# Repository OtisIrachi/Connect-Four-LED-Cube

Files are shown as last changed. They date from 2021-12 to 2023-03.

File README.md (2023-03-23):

# Connect four led cube
Connect Four Game using Wemos D1 Mini
4x4x4 LED Cube with encoder/PB to select game players and set moves.

Source Code, Schematic, Project Box STL Files, and BOM provided by RCI

Requires the following arduino library files:

Adafruit_NeoPixel.h

Adafruit_GFX.h

Adafruit_NeoMatrix.h

ESPRotarySet.h

connect4x4x4cubeschematic

connect4x4x4ledwiring

A few notes.....
1.  The WS2811 series LED's do not work well with WEMOS D1 GPIO outputs.  The digital output to the WS2811 is too low
    to reliably set the ws2811 shift register.  Remove the surface mount on-board rectifier diode (black diode near USB connector).
    Solder a jumper wire in its place.  The WEMOS D1 will now have enough voltage to drive the D-IN for the WS2811 LED's.
2.  Battery used in the project is a 3.7V 1000 mA lithium polymer, but any 3.7V 1000 mA battery will work. https://www.amazon.com/YTKavq-1000mAh-Battery-Rechargeable-Connector/dp/B08TTTL5BV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 
3.  Charger is a 1A USB Lithium Polymer Charger module, but any USB 1000ma charger will work.  https://www.amazon.com/CHENBO-Lithium-Battery-Charging-Protection/dp/B06XCXPY86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
4.  Proto board that fits in STL Case was found at Amazon, https://www.amazon.com/ElectroCookie-Prototype-Snappable-Electronics-Gold-Plated/dp/B081QYPHHP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

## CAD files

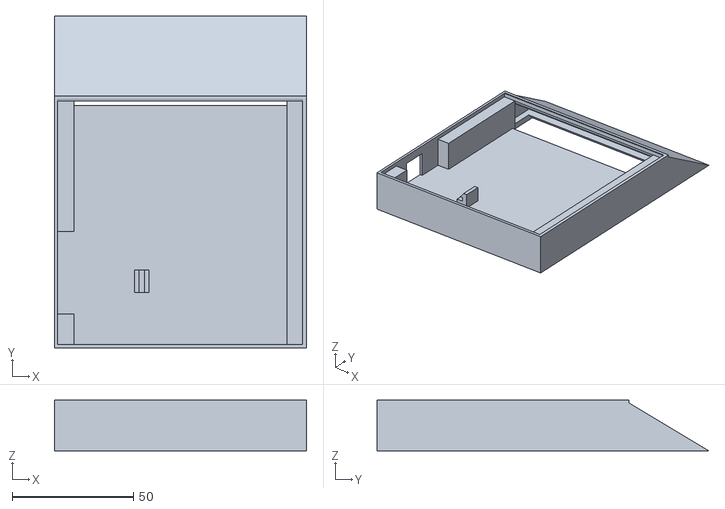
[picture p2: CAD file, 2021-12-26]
NeoCube Base.stl
104.0 x 137.0 x 21.0

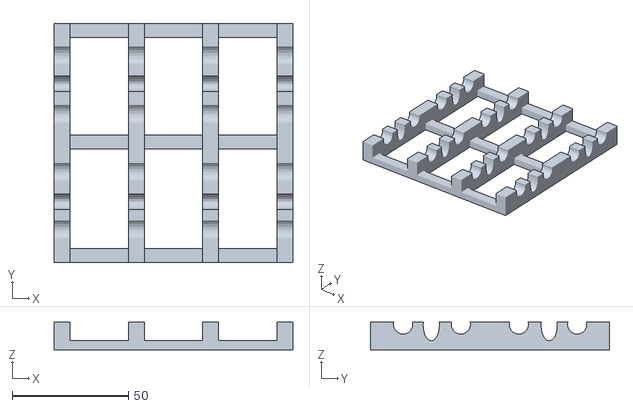
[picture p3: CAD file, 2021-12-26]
LED Jig Side.stl
103.0 x 103.0 x 12.0

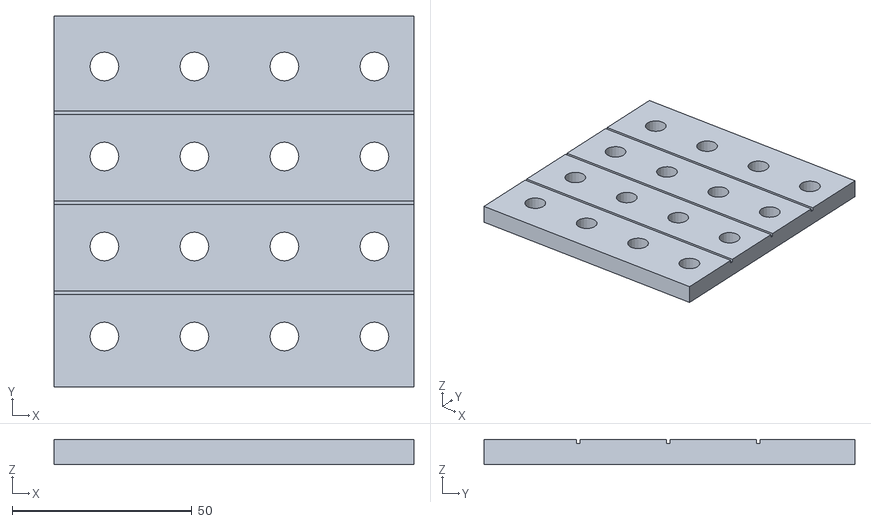
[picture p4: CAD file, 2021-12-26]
LED Jig 8mm.stl
100.0 x 103.0 x 7.00

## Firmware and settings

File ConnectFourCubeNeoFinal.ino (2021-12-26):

//*******************************************************************************
// ConnectFourCubeNeoFinal.ino
// Progressive Version of the Cube
// Connect Four RGB Cube Game
// If encoder has threads on shaft, use ESPRotarySet.h
// by RCI
//
// Edits:
//      10-11-2016
//         Added Player color choice check and flash yellow when same color selected.
//      3-18-2017
//         Cleaned up variable types,  reversed encoder direction - RCI.
//      12-24-2019
//         Fixed counter loop issue while displaying random rain - RCI.
//      11-10-2020
//         Added RefreshCube() call to FlashRow Routine.  Not sure why flash stopped
//         working - RCI.
//      12-24-2020 Changed EncoderHalfStep.h to ErriezRotaryHalfStep.h
//      1-16-2021 Redesigned cube for WS2812 Neopixels  
//      8-9-2021 Changed Encoder Driver to ESPRotarySet.h for threaded shaft type
//                ESPRotarySet added setPosition(int pos)
//*******************************************************************************
#include <Adafruit_NeoPixel.h>
#include <Adafruit_GFX.h>
#include <Adafruit_NeoMatrix.h>
//#include <ErriezRotaryHalfStep.h> 
#include <ESPRotarySet.h>
//***** Variables **************************
unsigned char flag;
unsigned char pos, next_slot, current_pos, last_pos;
unsigned char result;
signed int EncVal;
signed int countLast = 0;
unsigned char ColorChoice;
unsigned char next_player;
unsigned int counter;
unsigned int buttoncount;
unsigned char player;
unsigned char win[5];
unsigned char PlayerColor[3][3];
unsigned char MemoryColors[66][4]; 

#define PIN 4            // D2
#define BUTTON 14        // D5
#define ROTARY_PIN1  12  // D7
#define ROTARY_PIN2  13  // D6
#define CLICKS_PER_STEP   4   // this number depends on your rotary encoder 

#define MATRIX_WIDTH 4
#define MATRIX_HEIGHT 4
#define STARTING_PIXEL 1
#define MIN_ENC_VAL 1
#define MAX_ENC_VAL 64

#define LED_COUNT 64
#define num_of_pixels 64  //(sacrificial LED)

#define red       255, 0, 0
#define green     0, 255, 0
#define blue      0, 0, 255
#define black     0 ,0, 0
#define grey      1, 1, 1
#define dimwhite  1, 1, 1
#define midwhite  127, 127, 127
#define white     255, 255, 255
#define coolwhite 255, 255, 255
#define yellow    255, 138, 0
#define cyan      0, 255, 255
#define magenta   255, 0, 255
#define gold      255, 90, 0
#define orange    220, 40, 0
#define olive     100, 220, 47
#define turq      35, 255, 30
#define lime      15, 70, 10
#define skyblue   65, 176, 255
#define purple    70, 0, 120

//Matrix to Cube mapping 
unsigned char ZX[5][4]= 
{ 
 {0,0,0,0},
 {4,4,4,4},
 {8,8,8,8},
 {12,12,12,12}
};

//****************************************************                           
const unsigned char TempPos[65][4] = {
                            {0, 0, 0, 0},  // dummy
                            {0, 0, 0, 0},  // 1
                            {0, 1, 0, 0},  // 2
                            {0, 2, 0, 0},  // 3
                            {0, 3, 0, 0},  // 4
                            {0, 0, 1, 0},  // 5
                            {0, 1, 1, 0},  // 6
                            {0, 2, 1, 0},  // 7
                            {0, 3, 1, 0},  // 8
                            {0, 0, 2, 0},  // 9
                            {0, 1, 2, 0},  // 10
                            {0, 2, 2, 0},  // 11
                            {0, 3, 2, 0},  // 12
                            {0, 0, 3, 0},  // 13
                            {0, 1, 3, 0},  // 14
                            {0, 2, 3, 0},  // 15
                            {0, 3, 3, 0},  // 16 
                            {1, 0, 0, 0},  // 1
                            {1, 1, 0, 0},  // 2
                            {1, 2, 0, 0},  // 3
                            {1, 3, 0, 0},  // 4
                            {1, 0, 1, 0},  // 5
                            {1, 1, 1, 0},  // 6
                            {1, 2, 1, 0},  // 7
                            {1, 3, 1, 0},  // 8
                            {1, 0, 2, 0},  // 9
                            {1, 1, 2, 0},  // 10
                            {1, 2, 2, 0},  // 11
                            {1, 3, 2, 0},  // 12
                            {1, 0, 3, 0},  // 13
                            {1, 1, 3, 0},  // 14
                            {1, 2, 3, 0},  // 15
                            {1, 3, 3, 0},  // 16 
                            {2, 0, 0, 0},  // 1
                            {2, 1, 0, 0},  // 2
                            {2, 2, 0, 0},  // 3
                            {2, 3, 0, 0},  // 4
                            {2, 0, 1, 0},  // 5
                            {2, 1, 1, 0},  // 6
                            {2, 2, 1, 0},  // 7
                            {2, 3, 1, 0},  // 8
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
                            }; 

//****************************************************  
unsigned char LEDPos[65][4] = {
                            {0, 0, 0, 0},  // dummy
                            {0, 0, 0, 0},  // 1
                            {0, 1, 0, 0},  // 2
                            {0, 2, 0, 0},  // 3
                            {0, 3, 0, 0},  // 4
                            {0, 0, 1, 0},  // 5
                            {0, 1, 1, 0},  // 6
                            {0, 2, 1, 0},  // 7
                            {0, 3, 1, 0},  // 8
                            {0, 0, 2, 0},  // 9
                            {0, 1, 2, 0},  // 10
                            {0, 2, 2, 0},  // 11
                            {0, 3, 2, 0},  // 12
                            {0, 0, 3, 0},  // 13
                            {0, 1, 3, 0},  // 14
                            {0, 2, 3, 0},  // 15
                            {0, 3, 3, 0},  // 16 
                            {1, 0, 0, 0},  // 1
                            {1, 1, 0, 0},  // 2
                            {1, 2, 0, 0},  // 3
                            {1, 3, 0, 0},  // 4
                            {1, 0, 1, 0},  // 5
                            {1, 1, 1, 0},  // 6
                            {1, 2, 1, 0},  // 7
                            {1, 3, 1, 0},  // 8
                            {1, 0, 2, 0},  // 9
                            {1, 1, 2, 0},  // 10
                            {1, 2, 2, 0},  // 11
                            {1, 3, 2, 0},  // 12
                            {1, 0, 3, 0},  // 13
                            {1, 1, 3, 0},  // 14
                            {1, 2, 3, 0},  // 15
                            {1, 3, 3, 0},  // 16 
                            {2, 0, 0, 0},  // 1
                            {2, 1, 0, 0},  // 2
                            {2, 2, 0, 0},  // 3
                            {2, 3, 0, 0},  // 4
                            {2, 0, 1, 0},  // 5
                            {2, 1, 1, 0},  // 6
                            {2, 2, 1, 0},  // 7
                            {2, 3, 1, 0},  // 8
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
                            };
 
//****************************************************  
unsigned char Compare[77][4] = {
                            {0, 0, 0, 0},     // 0                           
                            {1, 18, 35, 52},  // 2
                            {5, 22, 39, 56},  // 3
                            {9, 26, 43, 60},  // 5 
                            {13, 30, 47, 64}, // 7
                            {4, 19, 34, 49},  // 4
                            {8, 23, 38, 53},  // 4
                            {12, 27, 42, 57}, // 6
                            {16, 31, 46, 61}, // 8                                                      
                            {1, 21, 41, 61},  // 0
                            {2, 22, 42, 62},  // 9
                            {3, 23, 43, 63},  // 10
                            {4, 24, 44, 64},  // 11
                            {16, 28, 40, 52}, // 12
                            {15, 27, 39, 51}, // 13
                            {14, 26, 38, 50}, // 14
                            {13, 25, 37, 49}, // 15
                            {1, 6, 11, 16},   // 16 
                            {4, 7, 10, 13},   // 1
                            {17, 22, 27, 32}, // 2
                            {20, 23, 26, 29}, // 3
                            {33, 38, 43, 48}, // 4
                            {36, 39, 42, 45}, // 5
                            {49, 54, 59, 64}, // 6
                            {52, 55, 58, 61}, // 7
                            {1, 22, 43, 64},  // 8
                            {16, 27, 38, 49}, // 9
                            {4, 23, 42, 61},  // 10
                            {13, 26, 39, 52}, // 11
                            {1, 2, 3, 4},     // 12
                            {5, 6, 7, 8},     // 13
                            {9, 10, 11, 12},  // 14
                            {13, 14, 15, 16}, // 15
                            {17, 18, 19, 20}, // 16 
                            {21, 22, 23, 24}, // 1
                            {25, 26, 27, 28}, // 2
                            {29, 30, 31, 32}, // 3
                            {33, 34, 35, 36}, // 4
                            {37, 38, 39, 40}, // 5
                            {41, 42, 43, 44}, // 6
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
                            };                                                        
unsigned char colors[10][3] = {
                            {255, 0, 0},     // red
                            {0, 0, 255},     // blue
                            {0, 255, 0},     // green                           
                            {255, 255, 255}, // white
                            {255, 255, 0},   // yellow
                            {255, 0, 255},   // magenta
                            {0, 255, 255},   // cyan                      
                            {255, 30, 0},    // orange 
                            {255, 100, 0},   // gold
                            {14, 255, 10},   // lime                                                 
                            }; 

//RotaryHalfStep rotary(ROTARY_PIN1, ROTARY_PIN2);
ESPRotary r = ESPRotary(ROTARY_PIN1, ROTARY_PIN2, CLICKS_PER_STEP);

Adafruit_NeoMatrix matrix = Adafruit_NeoMatrix(MATRIX_WIDTH, MATRIX_HEIGHT, 4, 1, PIN,
                            NEO_TILE_TOP + NEO_TILE_LEFT + NEO_TILE_ROWS + NEO_TILE_PROGRESSIVE +
                            NEO_MATRIX_TOP + NEO_MATRIX_LEFT +
                            NEO_MATRIX_ROWS + NEO_MATRIX_PROGRESSIVE,
                            NEO_RGB + NEO_KHZ800);
/*
Adafruit_NeoMatrix matrix = Adafruit_NeoMatrix(MATRIX_WIDTH, MATRIX_HEIGHT, 4, 1, PIN,
                            NEO_TILE_TOP + NEO_TILE_LEFT + NEO_TILE_ROWS + NEO_TILE_ZIGZAG +
                            NEO_MATRIX_TOP + NEO_MATRIX_LEFT +
                            NEO_MATRIX_ROWS + NEO_MATRIX_ZIGZAG,
                            NEO_RGB + NEO_KHZ800);                            
*/
Adafruit_NeoPixel strip = Adafruit_NeoPixel(num_of_pixels, PIN, NEO_RGB + NEO_KHZ800);
//*********************************************************************************
//#if defined(ARDUINO_ARCH_ESP8266) || defined(ARDUINO_ARCH_ESP32)
//ICACHE_RAM_ATTR
//#endif
//*********************************************************************************
void rotate(ESPRotary& r) 
{

    EncVal = r.getPosition();
        // Assign countLast value when EncVal is changed
        // Limit count to a minimum and maximum value
        if (EncVal >= MAX_ENC_VAL) 
           {
           EncVal = MAX_ENC_VAL;  
           //r.setPosition(MAX_ENC_VAL);         
           }
        if (EncVal <= MIN_ENC_VAL) 
           {
           EncVal = MIN_ENC_VAL;
           //r.setPosition(MIN_ENC_VAL);
           }    
    if (countLast != EncVal) 
        {
        countLast = EncVal;
        }
       
}
//************************************************************************************************
// delayms (loops) Milliseconds if using ESPAlexa
void delayms(int loops) 
{
unsigned long time_now = 0;
    time_now = millis();
    
    while(millis() < time_now + loops)
      {
      r.loop();  
      delay(1);   
      }  
}
//***********************************************************************************
void InitVariables() 
{
  EncVal = 0;
  countLast = 0;
  counter = 0;
  next_player = 0;
  buttoncount = 0;
  win[0] = 0;
  win[1] = 0;
  win[2] = 0;
  win[3] = 0;
  win[4] = 0;
  next_slot = 0;
  pos = 1;
  flag = 0;
  matrix.fillScreen(0);
  RefreshCube();
}
//*******************************************************************************************  
// Rain Random Colors Upward
void RandomColor()
{
unsigned char xa, ya, x1, y1, x2, y2, y3, tempcolor, tempcolor1, tempcolor2, zpos;

 if(digitalRead(BUTTON) != 0)
    {
    while(digitalRead(BUTTON) != 0)   // Repeat
       {
          xa = random(4);
          ya = random(4);
          x1 = random(4);
          y1 = random(4);
          x2 = random(4);
          y3 = random(4);
          tempcolor = random(12);
          tempcolor1 = random(12);
          tempcolor2 = random(12);
          for(zpos = 0; zpos < 4; zpos++)
             {
             setPixelZXY(zpos, xa, ya, colors[tempcolor][0], colors[tempcolor][1], colors[tempcolor][2]);
             setPixelZXY(zpos + 1, x1, y1, colors[tempcolor1][0], colors[tempcolor1][1], colors[tempcolor1][2]);
             setPixelZXY(zpos + 2, x2, y2, colors[tempcolor2][0], colors[tempcolor2][1], colors[tempcolor2][2]);
             setPixelZXY(zpos + 3, xa, y3, colors[tempcolor2][0], colors[tempcolor2][1], colors[tempcolor2][2]);
             matrix.show();
             delayms(80);
             matrix.fillScreen(0);
             }
          if(digitalRead(BUTTON) == 0)
             {
             while(digitalRead(BUTTON) == 0)   
                {             
                }
                counter = 0;
                ClearCube();
                next_player = 0;
                delayms(2000);
                return;
                } 
       }
    }
}
//***********************************************************************************
void FlashRow(unsigned char pos1, unsigned char pos2, unsigned char pos3, unsigned char pos4)
{
    while(digitalRead(BUTTON) != 0)   // Hold Here
       {                 
       setPixelZXY(LEDPos[pos1][0], LEDPos[pos1][1], LEDPos[pos1][2], MemoryColors[pos1][0], MemoryColors[pos1][1],MemoryColors[pos1][2]);
       setPixelZXY(LEDPos[pos2][0], LEDPos[pos2][1], LEDPos[pos2][2], MemoryColors[pos2][0], MemoryColors[pos2][1],MemoryColors[pos2][2]);
       setPixelZXY(LEDPos[pos3][0], LEDPos[pos3][1], LEDPos[pos3][2], MemoryColors[pos3][0], MemoryColors[pos3][1],MemoryColors[pos3][2]);
       setPixelZXY(LEDPos[pos4][0], LEDPos[pos4][1], LEDPos[pos4][2], MemoryColors[pos4][0], MemoryColors[pos4][1],MemoryColors[pos4][2]);
       matrix.show();
       RefreshCube();
       delayms(500);
       setPixelZXY(LEDPos[pos1][0], LEDPos[pos1][1], LEDPos[pos1][2], 0, 0, 0);
       setPixelZXY(LEDPos[pos2][0], LEDPos[pos2][1], LEDPos[pos2][2], 0, 0, 0);
       setPixelZXY(LEDPos[pos3][0], LEDPos[pos3][1], LEDPos[pos3][2], 0, 0, 0);
       setPixelZXY(LEDPos[pos4][0], LEDPos[pos4][1], LEDPos[pos4][2], 0, 0, 0); 
       matrix.show();     
       delayms(500);        
       }
    delayms(2000);
}
//***********************************************************************************
void FlashError(unsigned char pos1)
{
int a;

    for(a = 0; a < 5; a++)
      {
      setPixelZXY(TempPos[pos1][0], TempPos[pos1][1], TempPos[pos1][2], 255, 255, 0);
      matrix.show();  
      delayms(500);
      setPixelZXY(LEDPos[pos1][0], LEDPos[pos1][1], LEDPos[pos1][2], MemoryColors[pos1][0], MemoryColors[pos1][1], MemoryColors[pos1][2]);
      matrix.show();  
      delayms(500);      
      }   
}
//************************************************************************************************************************************* 
void RefreshCube()
{
  int CubePos;
  
    for(CubePos = 1; CubePos < LED_COUNT + 1; CubePos++)
      {  
      setPixelZXY(LEDPos[CubePos][0], LEDPos[CubePos][1], LEDPos[CubePos][2], MemoryColors[CubePos][0], MemoryColors[CubePos][1],MemoryColors[CubePos][2]); 
      }
    matrix.show();       
} 
//***********************************************************************************
void ClearCube()
{
int a, b, c;

   for(a = 0; a < 5; a++)
     { 
     for(b = 0; b < 5; b++)
       {
       for(c = 0; c < 5; c++)
         {
         setPixelZXY(a, b, c, 0, 0, 0); //uses 24bit RGB color Code
         }    
       }      
     }      
   matrix.show();    
   for(a = 0; a < 65; a++)
     { 
     LEDPos[a][3] = 0;
     }
     
   for(a = 0; a < 65; a++)
     {
     for(b = 0; b < 4; b++)
        {       
        MemoryColors[a][b] = 0;
        }
     }   
   countLast = 1;
   next_player = 0;
   buttoncount = 0;     
}
//***********************************************************************************
void ClearPixel(unsigned char x, unsigned char y, unsigned char z)
{
      setPixelZXY(z, x, y, 0, 0, 0);
}
//***********************************************************************************
void SelectColor(unsigned char r, unsigned char g, unsigned char b, unsigned pos)
{
      setPixelZXY(TempPos[pos][0], TempPos[pos][1], TempPos[pos][2], r, g, b); 
      matrix.show();       
}
//***********************************************************************************
void SelectPixel(unsigned char r, unsigned char g, unsigned char b, unsigned pos)
{
      setPixelZXY(TempPos[pos][0], TempPos[pos][1], TempPos[pos][2], 0, 0, 0);
      matrix.show();
      delayms(50);
      setPixelZXY(TempPos[pos][0], TempPos[pos][1], TempPos[pos][2], r, g, b); 
      matrix.show();
      delayms(50);  
          
}
//***********************************************************************************
//set the pixel (Z,X,Y) of RGB Cube with colours R,G,B 
void setPixelZXY(unsigned char zaxis, unsigned char x, unsigned char y, unsigned char r, unsigned char g, unsigned char b) 
{     
     matrix.drawPixel(ZX[zaxis][x] + x, y, matrix.Color(r, g, b));
     
}
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
void loop()
{
  r.loop();
  //*** Increment Next Axis ***
  if(digitalRead(BUTTON) == 0)
    {
    while(digitalRead(BUTTON) == 0)   // Hold Here
        {        
        ++buttoncount;
        delayms(100);
        if(buttoncount >= 20) 
           {
           ClearCube();
           InitVariables();
           RefreshCube();  
           buttoncount = 0;
           next_player = -1;
           while(digitalRead(BUTTON) == 0)   // Hold Here
           {}           
           break;
           }        
        }//End While          
                                                 
    ++next_player;    
    if(next_player >= 5) next_player = 1;     
    RefreshCube();         
    }// End if 
  // *************************  
  if(buttoncount >= 5) buttoncount = 0; 
  if(next_player >= 5) next_player = 1;
  RefreshCube();

//***********************************************************       
        switch(next_player)
           {
           case 0:   // Wait for First Move *****************

                SetPlayerColor();
                RefreshCube();

           break;
           
           case 1:   // Player One Move **********************

                SelectPixel(PlayerColor[1][0], PlayerColor[1][1], PlayerColor[1][2], countLast); 
                player = 0;                              
 
           break;

           case 2:   // Set Red Pixel and Go To Player 2
                
                EncVal = 1; 
                SetMove(PlayerColor[1][0], PlayerColor[1][1], PlayerColor[1][2], countLast);
                ++buttoncount;                    
                
                r.setPosition(countLast);      
                EvaluateCube();
               
           break;
           
           case 3:   // Player Two Move ********************** 

                SelectPixel(PlayerColor[2][0], PlayerColor[2][1], PlayerColor[2][2], countLast);
                player = 1;
 
           break;
           
           case 4:   // Set Blue Pixel and Go Back *************** 

                EncVal = 1;
                SetMove(PlayerColor[2][0], PlayerColor[2][1], PlayerColor[2][2], countLast);
                ++buttoncount;                      
                
                r.setPosition(countLast);
                EvaluateCube();

           break;                                                                 
           }//End Switch
//***********************************************************    
           
}//End Loop
//**************************************************************************************************************
